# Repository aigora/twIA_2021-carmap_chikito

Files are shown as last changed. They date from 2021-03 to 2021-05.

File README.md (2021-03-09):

# CarMap - Chikito

Robot inalámbrico por Bluetooth que se conecta al ordenador. Con un teclado de macros o el mismo del ordenador se puede manejar. Además, el ordenador tiene en cuenta la trayectoria del robot para poder automatizar su vuelta. Dicha trayectoria se muestra en la pantalla, bien sea en forma del vector posición y rotación o mediante una curva.

## Integrantes del equipo

- Echedey Luis Álvarez. @echedey-luis-alvarez
- Fernando Moreno Santa Cruz. @Fer014
- Amélie Nader Prieto. @amelie-nader-prieto
- Luis Fernando Rubio Regojo. @luisrubio27
- Lucas Sánchez Solera. @luc-39
- Celia Torrecillas Barba. @Celia-t22

## Objetivos del trabajo

### Objetivos principales y mínimos:
- [] Crear un teclado de macros que simule un teclado usual.
- [] Hacer un pequeño robot inalámbrico por Bluetooth.
	- [] Capaz de moverse hacia delante y hacia atrás, y rotar sobre sí mismo. Se usarán drivers con motores DC.
- [] Hacer un programa en un ordenador que sea el intermediario entre cualquier método de entrada, como el teclado de macros, y el robot.
	- [] Estimar la posición del robot en cada momento según los comandos que envíe el programa.
	- [] Mostrar en alguna forma de interfaz la ubicación y rotación del robot.

### Objetivos secundarios, mejoras:
- [] Control de rotación de cada rueda mediante optoacopladores o pares LED IR - Sensor IR.
- [] Algoritmo para que el robot pueda volver sobre sí mismo
- [] Sistema para guardar posición, rotación, velocidad, (template de un robot) en un fichero.

## TODO:
- [] Wiki
- [] Crear logo
- [] Crear diagramas de flujo

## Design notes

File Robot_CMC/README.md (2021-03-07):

# Programa del robot inalámbrico
Programa de Chikito.
Un programa que permita recibir ordenes por bluetooth para que Chikito se mueva en todas direcciones.
Estará compuesto de un motor DC y este a su vez moverá unas ruedas.
Chikito podrá avanzar, retroceder y girar sobre sí mismo. 
En cada momento enviará al ordenador su posición para que se pueda crear su gráfica de posición.

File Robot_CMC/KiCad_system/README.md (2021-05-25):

# Sistema electrónico del Robot
En esta carpeta se encuentra el proyecto en KiCad del Robot _Chikito_. Se utilizan librerías personalizadas que se pueden encontrar en [este enlace](https://github.com/echedey-luis-alvarez/My_KiCad_Libraries).

Solo se emplea para exportar el esquema electrónico a imagen y realizar las explicaciones pertinentes.

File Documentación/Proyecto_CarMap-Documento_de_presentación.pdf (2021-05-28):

twIA_2021-CarMap_Chikito
Presentación del proyecto

# CarMap - Documentación

Repositorio: https://github.com/aigora/twIA_2021-carmap_chikito

## Miembros del grupo

Tag de GitHub en paréntesis
- Echedey Luis Álvarez (@echedey-luis-alvarez)
- Fernando Moreno Santa Cruz (@Fer014)
- Amelie Nader Prieto (@amelie-nader-prieto)
- Luis Fernando Rubio Regojo (@luisrubio27)
- Celia Torrecillas Barba (@Celia-t22)
- Lucas Sánchez Solera (@luc-39)
Todos (somos) estudiantes de primer año de Electrónica (grupo A109)

## Índice

- El proyecto
- Descripción del sistema
- Algoritmos
- Funciones y librerías
- Modificaciones del documento
- Enlaces de interés

# El proyecto CarMap

## Propósito del proyecto

Aunque a priori parece un proyecto cutre de estudiantes de primero de carrera (lo es) pretendíamos crear una aproximación bastante aproximada de lo que podría ser un robot que pueda ayudar en eventos catastróficos, en lugares que suponen un riesgo alto para los humanos. Sobra decir que el proyecto se queda lejos de la realidad, porque ni el Arduino UNO, ni nuestro tiempo ni nuestro nivel dan para tanto (por ahora).
Esencialmente no tiene mucha más utilidad que la de moverlo por un sitio e ir registrando su camino. Con este algoritmo, se podría estimar su posición, o moverse por sí mismo siguiendo una línea, tal vez llegar a volver por sí solo.

## Problema a resolver

Concretamos al principio del proyecto que este se trataría de un robot similar a un coche tele-dirigido y cuyo algoritmo le permite que su trayectoria se guarde en un mapa (fichero) y que el robot pueda “recordar” su trayectoria para poder regresar por el mismo camino que hizo. Además, queremos que sea fácil de manejar, para lo que intentaremos hacer algo similar a un mando radio-control.
Posteriormente consideramos que debido a la limitación del hardware y los requerimientos de la tarea, principalmente porque hay que manejar ficheros, lo que mejor se adapta es gestionar comandos y todo lo relativo a propiedades del robot en el PC, enviarlos y que el robot los ejecute.

# Descripción del sistema

Nuestro programa cuenta con tres subsistemas: por un lado haremos un teclado de macros (o HID, Human Interface Device) que permita manejar el robot. Por otra parte, un programa en el ordenador que tendrá el algoritmo más profundo en cuanto a manejar datos: entrada por teclado de los movimientos que hacer, exponer en la pantalla un mapa con los movimientos que va realizando el robot y algún otro dato, enviar datos al robot por Bluetooth y gestionar un fichero con la trayectoria. Finalmente, el robot, que deberá moverse en función de los comandos recibidos por Bluetooth.
En nuestro repositorio de GitHub se pueden ver varias carpetas. Estas son las que contienen a los códigos de los distintos subsistemas que hemos definido:
- Para el teclado de macros (HID): Teclado_Macros/
- Para el programa del PC: Mapeador/
- Para el robot: Robot_CMC/

Tanto el teclado de macros como el robot funcionan con Arduino. Asimismo, se programará el Mapeador en C con Visual Studio, aunque también tiene código en C++ para usar clases; en el mismo ejemplo de conexión por Bluetooth se utiliza la clase String, y en el Mapeador porque en las biblioteca SerialClass.h; también para la propia conexión se utiliza una clase.
Planteamos los problemas a resolver por distintas partes del proyecto antes mencionadas: el teclado de macros o HID, el programa en el PC (Mapeador), y el robot, que hemos querido bautizar como Chikito por cuestiones de marketing.

## Descripción detallada e identificación de sensores y actuadores

Este apartado fue escrito inicialmente en la Wiki del proyecto en GitHub después de discutir el tema entre todos en varias reuniones.

### Robot

- El Arduino se conecta al ordenador por Bluetooth
- Lucas Sánchez (@luc-39) se encarga del código en el Arduino.
■ Para poder conectar el software de Arduino con la placa que se encontrará en el robot es necesario usar un módulo bluetooth HC-05 que se encontrará en la protoboard. Además será necesario hacer uso de SoftwareSerial.h.
■ @Celia-t22 se encarga del movimiento de los motores mediante funciones.
- Se pueden incluir sensores como opto acopladores para monitorizar el giro de las ruedas. Al final esta parte no procede.

Para completar la información relacionada con el robot se utilizará el pdf

[3] de moodle
sobre la comunicación con Arduino y PC mediante bluetooth y la página
[4] sobre cómo usar
Arduino y C++.

### Mapeador

Tras una profunda lluvia de ideas se asignaron las siguientes tareas:
- Añadir función que calcule ángulo entre 2 vectores en vector.h para @Fer014.
- Maquetar una librería con propiedades del robot, de forma genérica, para alterarlas de forma más cómoda. Para @Fer014.
- Empezar con la entrada de comandos desde el teclado, que realizará @luisrubio27 con ayuda de la librería time.h.
- Se crearán vectores que se añaden a un array.
- Estos vectores dependen de la tecla; la dimensión del array, del tiempo presionado.
■ Sólo las teclas asociadas al movimiento (posición) del robot responden continuamente al mantenerse presionadas; en este proceso entran los vectores de posición y el tiempo total en el que la tecla se mantiene pulsada. Por tanto, los sensores serán el teclado del PC y el teclado de macros. No habrán actuadores per se, pero sí operaciones con los vectores y salida por la consola.

### Teclado de macros

Esta parte tiene que ser sencilla, implementando solo entradas digitales (pulsadores) y cuya actuación simula la pulsación de botones del teclado (conceptualmente, la actuación es una función programada, la cual puede ser pulsar una tecla o varias o hacer cualquier cosa más compleja). Desarrollándose por Amélie (@amelie-nader-prieto).
En resumen los sensores son los pulsadores del teclado y el actuador es la comunicación con el ordenador.

## Diseño del sistema por subsistemas

El contenido de este apartado fue también escrito inicialmente en GitHub tras una reunión del grupo, pero se ha actualizado ligeramente al ponerlo aquí.
Trabajamos en este paso a partir de las especificaciones hechas en la tarea anterior, de nuevo teniendo en cuenta los requisitos funcionales y no funcionales de hardware y código de las distintas partes del proyecto. Previamente a esta tarea definimos los datos que se manejan en distintas funciones del programa y se profundizó más en asuntos del hardware; en esta tarea nos interesa más trabajar en el software de nuestro proyecto; tanto en la estructura del programa principal ejecutado en el ordenador como en las aplicaciones de las plataformas auxiliares (robot y teclado).
En esta segunda reunión del equipo de desarrollo nos interesamos en aclarar, organizar y establecer los límites en el proceso de desarrollo que llevaremos individualmente sin perder de vista el trabajo en equipo. Necesitamos mantener cohesionado el proyecto y asegurar que las conexiones entre cada parte sean sólidas. A continuación exponemos en qué parte de la línea de la información se centra cada miembro, en función de cada apartado del proyecto:

### HID / Teclado de Macros

En la aplicación de PC para el teclado de macros se realizan las tareas de monitorización de las señales mediante funciones de SerialClass.h.
- Especificaciones y desarrollo por Amélie (@amelie-nader-prieto). Esta parte es la más simple en el código, pero se comunica directamente con el programa principal, y finalmente sirve como un dispositivo para controlar manualmente el robot.
- Las funciones (macros) aparecen programadas en el código de Arduino, y en la primera versión del proyecto se limitan a pulsar teclas.
- Para este propósito se puede considerar prescindible un teclado de macros, pero siempre se puede mejorar el código para que se puedan hacer funciones más complicadas del programa.
- Se utiliza la librería de Arduino Keyboard.h para utilizar el teclado, mediante funciones en las que no se pasan valores.

[9]

### Mapeador

En esta parte del proyecto establecemos aquellas funciones principales que queremos que se gestionen en el PC. Las partes más importantes son la entrada de datos mediante el teclado de macros, los cálculos relacionados con el Robot (el algoritmo), la escritura de ficheros, y la comunicación (envío de datos) por el puerto serie Bluetooth con el Robot.
- Especificaciones y desarrollo por @luisrubio27
- i. Diseñar el mapeador a través de la función gotoxy para imprimir un mapa que de a entender el recorrido del robot. Que se sitúe centralizado en la pantalla.
- ii. Diseñar el sistema brújula para que introduciendo las letras n, o, s, e se mueve en esa dirección tanto el mapa como el robot.
- iii. Introducir los datos de entrada para conectar el mapa con el algoritmo. Para posterior desarrollo de @Fer014.
- Especificaciones y desarrollo por @Fer014
i. Calcular el movimiento de las ruedas del robot, su avance y rotación, a partir de los datos recibidos y de la biblioteca "robot.h".
ii. Calcular las coordenadas de la posición del robot, para su posterior uso por @echedey-luis-alvarez.
- Especificaciones y desarrollo por @echedey-luis-alvarez
i. Escritura en fichero de los puntos por los que pasa el robot. Los puntos se toman del código a cargo de @Fer014 .
ii. Envío de datos por Bluetooth. Se acuerda entre todo el equipo que al robot se le pasará la cantidad de tiempo y el sentido en que debe girar cada rueda. Más concretamente, el formato de la cadena con el que se envía la información se aclarará con @luc-39 .

### Robot

- Especificaciones y desarrollo por @luc-39
i. Recibir los datos por Bluetooth desde el ordenador con ayuda de la librería SoftwareSerial.h. Para poder conectar el programa del ordenador con el del Arduino se verá con @echedey-luis-alvarez.
ii. Enviar la información recibida a @Celia-t22 y que así pueda operarse la última parte del código.
- Especificaciones y desarrollo por @Celia-t22
i. Recibo la información que manda @luc-39.
ii. Con esta información, los motores se moverán de forma que permita que Chikito se mueva en la dirección y el tiempo deseado.
iii. A continuación un esquema del movimiento de los motores:

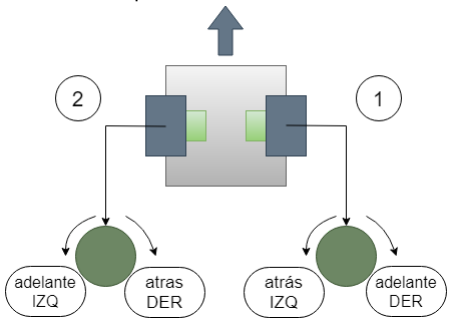
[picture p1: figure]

Este esquema representa los nombre que se le ha dado a cada movimiento en el código. Primero se ha puesto un nombre para cada distinguir cada motor, es decir “1” al motor que va a la derecha de chikito y “2” al que va la izquierda. Después, para representar si deseamos que la rueda gire hacia delante o hacia atrás, se ha representado como “IZQ” o como “DER”; estos nombre se han puesto así porque representan el lado que girará la rueda si se mira de frente.

## Entrada y salida de datos

Las entradas y salidas de datos se describen como una sucesión lineal entre las distintas partes del proyecto.

### Teclado de Macros

- Entrada: En el programa se realiza la lectura sucesiva de los pins digitales del controlador (los cuales son INPUT), y se guarda el valor (HIGH o LOW, donde LOW ocurre cuando el botón es pulsado) de todos ellos en un vector.

- Salida: El programa de Arduino no tiene datos de salida pues sus funciones no devuelven ningún valor, sino que pulsan las teclas N,S,E,O, que son las “flechas direccionales” con las que se dirigirá el robot en su movimiento. La salida no es un dato realmente, sino una acción que se realiza según los datos de entrada.
Dentro del mapeador están preparadas las bibliotecas y funciones más complejas que se ocupan de relacionar las señales recibidas del teclado con los comandos del robot (biblioteca de operaciones con vectores, biblioteca de propiedades del robot).

### Mapeador

- El programa recibe los datos digitales del teclado y realiza con ellos las funciones correspondientes.
- Se realizará un bucle switch/case con los comandos correspondientes a las teclas que realizan las funciones más básicas del robot (la tecla de encendido y de cambio de perfiles)
- A partir de las coordenadas se genera un array de los vectores de posición del robot.

### Robot

- Las variables y/o constantes necesarias serán manejadas en la biblioteca de propiedades del robot localizada en el mapeador.
- En los inicios del proyecto se planteó crear una estructura asociada al robot (template del robot) con únicamente tres variables distintas, pero decidimos posponer la definición de una estructura para otro momento.
- La conexión entre el robot y el ordenador será inalámbrica (Bluetooth).
- El robot funciona con una Arduino UNO Rev3 y la conexión Bluetooth con el módulo Bluetooth HC-05;
Coincidimos en que las especificaciones en el modo en que los valores obtenidos son almacenados y transmitidos entre las partes del proyecto, empleando ficheros y definiendo arrays numéricos (matrices) y vectores de estructuras se deja para fases más avanzadas; sin embargo tenemos una idea de los datos que es crucial manejar en el programa para que este pueda realizar su objetivo.
- Posición en el espacio expresada en coordenadas cartesianas
- Posición
- Rotación: ángulo en radianes o vector dirección
- Velocidad de movimiento
- Falta concretar las componentes y si habrá aceleración
Ahora bien, la salida se hace por un par de motores. Estos se controlan mediante dos circuitos integrados LB1641

[5]
, unos drivers bidireccionales que se controlan mediante dos pines digitales cada uno.

## Esquema electrónico del robot

A continuación se explica el funcionamiento del sistema electrónico que le da vida al robot. Los recursos diseñados en KiCad se pueden consultar en el repositorio.

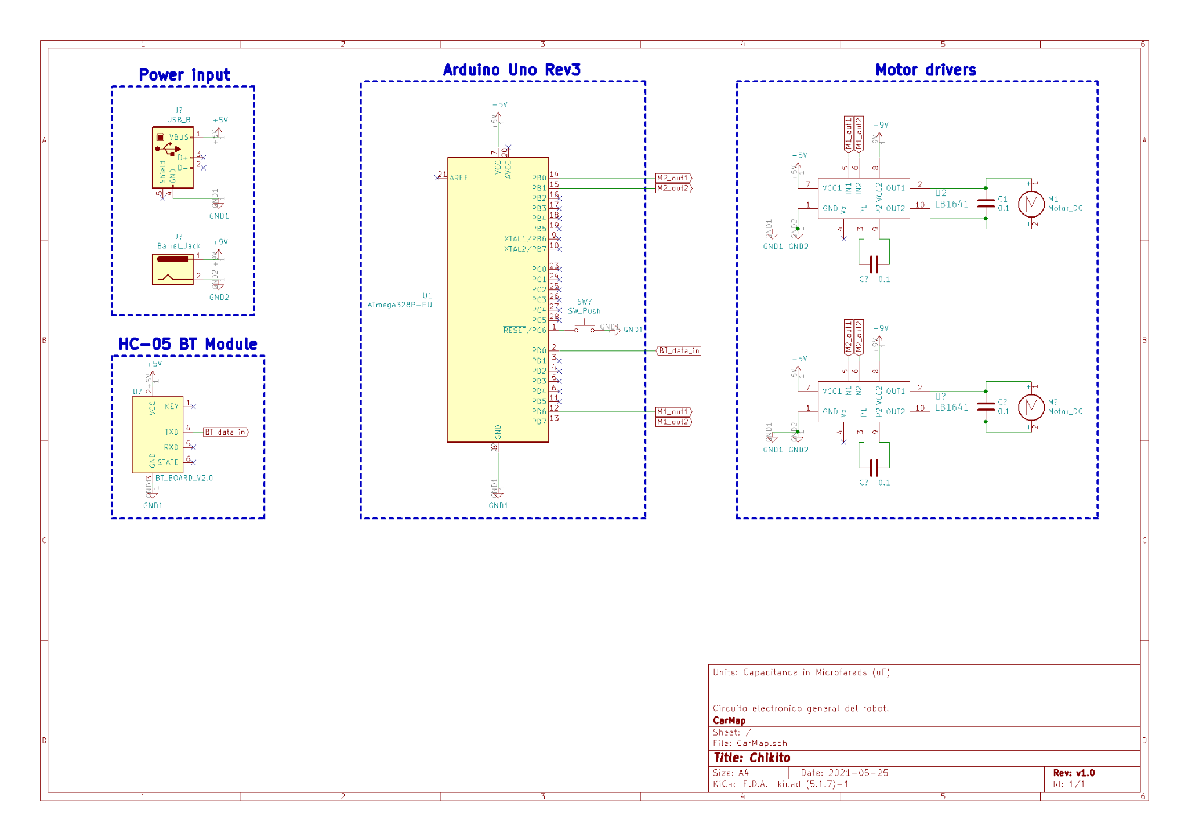
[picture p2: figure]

Lo que aquí se expone simplemente demuestra el funcionamiento del código, tal y como queda dicho en el vídeo, ya que no se ha probado con baterías y no se ha montado en una estructura, tan solo probado la parte electrónica.
Para comprobar la funcionalidad del sistema se han empleado:
1. Jumper wires para protoboard
2. Un par de protoboards
3. Un módulo Bluetooth de Keyestudio con el HC-05
4. Un Arduino UNO Rev3 con el chip ATmega328p
5. Un par de drivers LB1641 montados en una placa preperforada que contiene:
a. 2 drivers LB1641
b. 2 condensadores cerámicos de 0.01 uF
c. 2 condensadores cerámicos de 0.1 uF
d. Varios terminales para las conexiones oportunas
6. Un par de motores DC idénticos.

El circuito se monta tal y como viene en el previo diagrama electrónico.
1. En primer lugar, la potencia viene a 5V por un USB tipo B, que es el conectado al Arduino; y de algún otro voltaje (máximo 18V) para los motores
- se ha utilizado una fuente de red de 9V.

2. Los 5V alimentan la parte lógica: Arduino, módulo BT y el sistema lógico de los drivers.
3. La otra fuente alimenta la parte de potencia, es decir, los motores con los drivers de intermediarios.
4. Las señales lógicas que determinan en qué sentido se mueve cada motor son las que salen de los pines 6 a 9, dos por motor: como se puede consultar en el datasheet del LB1641

[5]
, cuando un pin está encendido y el otro apagado se mueve en un sentido. Si se intercambian estos pines, gira en el contrario. Si ambos están a nivel lógico HIGH o LOW no se mueven. Aunque no se especifica expresamente, se indica que en este último caso estarían en modo “Braking”, lo que implica que las salidas al motor estarían en corto y por autoinducción debería frenar antes.
5. Finalmente, el módulo Bluetooth se conecta desde su pin TXD (transmisión) al RX del Arduino (recepción), o sea, que el ATmega recibe la información enviada por el HC-05 que recibe desde el PC.

# Algoritmos y código como conjunto

A continuación se exponen cada una de las funciones que tienen lugar código. Para comentar cada librería que hemos creado o partes en específico que requieren más atención desde un punto de vista especialmente técnico vaya al apartado Funcionamiento de las distintas partes del código.

### Teclado de macros - HID

El HID funciona con un código escrito con el Arduino IDE y con un algoritmo no muy complejo.
1. El controlador se conecta con un cable al puerto COM3 del ordenador y es necesario conectarlo para que funcione el código.
2. En la función void loop() se realiza la lectura sucesiva de los pins digitales en los que están conectados los pulsadores, y guarda sus valores (HIGH o LOW) en un vector.
3. Si el programa detecta un LOW en la posición n del vector, llama a una función de parámetro n que se encarga de pulsar la tecla que corresponda mediante un switch. Esta función sirve para emular pulsaciones en el teclado del ordenador.
Y sobra ya decir que está incluida Keyboard.h.

Definiciones

#define N 6

#define S 7

#define E 8

#define O 9

Se definen los pins digitales que están conectados a cada pulsador, y que en la ejecución del programa son leídos sucesivamente al estar en un vector.
Además de estos, se podrían añadir otros botones asignados a cualquier otro pin del controlador (del 2 al 13), y programar funciones para ellos.
const int arrowpad[]={N,S,E,O};
Aunque es técnicamente una variable global, en Arduino no suele ser tan problemático porque se suelen manejar funciones que no modifican o devuelven valores numéricos. Además en este caso, tener definidas las constantes facilita la adición de nuevas teclas y funciones ya que la dimensión del vector arrowpad[] está declarado como const int, por lo cual se podría cambiar el vector sin tener que actualizar otras funciones o bucles.

Funciones
Son muy simples. Intenté hacer este programa corto, especialmente hacer la función principal (void loop()) lo más corta posible.
En setup() se inicializa el Serial, los pines del vector, y el teclado.
En loop() se realiza esta lectura sucesiva del vector con los botones, leyendo uno por uno los índices del vector, y si uno de ellos está pulsado, lo vuelve a leer y llama a, digamos la función del teclado;

key(i+1); donde el parámetro es una variable utilizada en el bucle donde se hacían estas lecturas; for(i=0;i<dim;i++){...} por lo cual i es el índice del vector en cada momento.
Esta es la función:
void key(int i){
switch(i){
case 1:north();break;
case 2:south();break;
case 3:east();break;
case 4:west();break;
default:break;
}
}
Y esas funciones llamadas en cada case son los comandos de Keyboard.h que pulsan las teclas en el ordenador; Keyboard.press(tecla); Keyboard.release(tecla); Los nombres de las teclas son valores definidos en Keyboard.h.

### Mapeador

Este programa utiliza una gran cantidad de librerías, ya que implementa muchas funcionalidades distintas entre sí; estas son:
Bibliotecas genéricas
1. stdio.h
a. Entrada básica de datos por consola (printf y scanf)
2. stdlib.h
a. Asignar memoria de forma dinámica
3. string.h
a. Permite realizar algunas operaciones con cadenas, se usa para crear los comandos del Robot.
4. wchar.h
a. Para utilizar caracteres “amplios”, i.e., que ocupan más de un byte. Esto se usa porque la biblioteca SerialClass.* nos daba un problema en el tipo de puntero al puerto utilizado que se pasaba al SO.
5. iso646.h
a. Posiblemente la librería que más aporte al programa: resulta más legible and, or y not que “&&”, “||” y “!” respectivamente. Sobre todo si vienes de Python.
6. math.h
a. Introduce las funciones trigonométricas y de redondeo que se usan para el mapa y el cómputo de coordenadas.
7. stdbool.h
a. Define los tipos bool si estás en C. En C++ ya vienen definidos. Esto es un poco por tontuna; es para la parte de crear los comandos, que tenga un poco el sentido binario que tiene, ya que se desplaza o rota, hacia delante o hacia atrás, hacia la izquierda o hacia la derecha.

8. conio.h
a. Introduce la función _getch() que permite tomar un carácter del búfer de entrada nada más se pulsa (como getchar(), pero esta última daba problemas y no funcionaba ubicar el búfer al final con
fseek(stdin, 0, SEEK_END) ).
9. windows.h
a. Para ubicar la posición del cursor en la consola ( gotoxy() ). Bibliotecas locales:
10. vector.h
a. Define la estructura vector2D y múltiples operaciones. Al final no se usa ni la mitad, pero aporta flexibilidad por si se quiere añadir alguna funcionalidad o refactorizar la parte del mapeador.
11. SerialClass/SerialClass.h
a. Añade la clase Serial (un tipo de dato de C++) para conectar por Bluetooth más fácilmente. Recuperada de https://github.com/Gmatarrubia/LibreriasTutoriales, modificada localmente.
12. waypoints_filehandler.h
a. Funciones que permiten inicializar, escribir y leer vectores del archivo de la trayectoria con el formato explicado en el apartado 2.4.1. Gestión del fichero en memoria.
En primer lugar se inicializa una ristra de variables que se utilizan durante la ejecución.
En segundo lugar, se le pide al usuario que indique por qué puerto COM se debe conectar al Arduino. Se intenta conectar, y si falla imprime el mensaje de error y se detiene la ejecución. Si es un éxito, se crea el archivo que va a guardar los vectores en binario y se inicializa. Si ocurriese algún error en esta parte, se detendría.
Si todo ha funcionado correctamente, imprime el estado del programa y los controles, para que el usuario sepa cómo proceder. Tras una pulsación que se haga en el teclado, se limpia lo escrito por pantalla, se inicializa el mapa y la posición del robot.
Una vez en el bucle, se espera a una pulsación del usuario, y si está definida (n, s, e, o) se crea un comando que se envía por Bluetooth. En caso contrario no se hace nada. Si se envía el comando, se cambia la posición en el mapa del robot y se vuelven a mostrar la posición, la distancia recorrida y la distancia desde el origen.
Por último, cada vez que se envía un comando se añade el vector al fichero y se espera el tiempo necesario a que espere de

### Robot

El esquema de la protoboard con el módulo bluetooth HC-05 sería el siguiente:

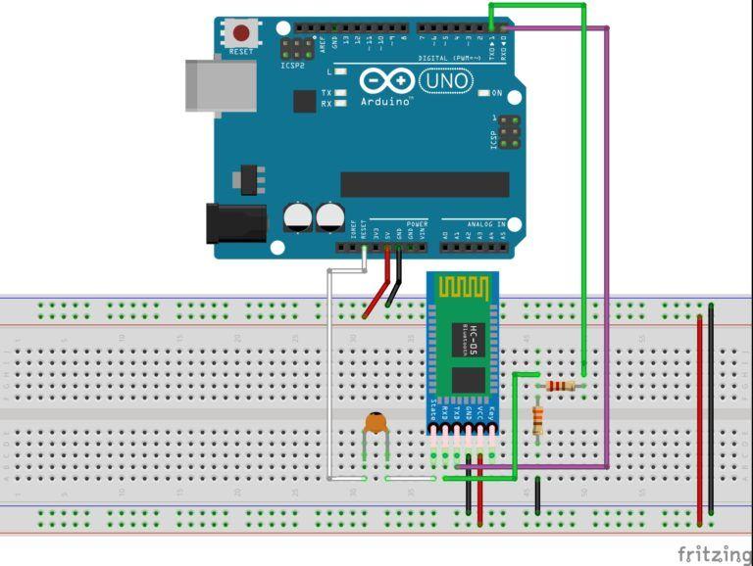
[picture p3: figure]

Anotación: Es necesario que la resistencia esté ya que del pin TX salen 5V y el módulo bluetooth HC-05 admite un voltaje más bajo, unos 3,3V.

Para poder configurar el módulo bluetooth se utilizan los comandos 'AT':

- 'AT+NAME'. Se define el nombre del dispositivo.
- 'AT+PSWD'. Se define la contraseña (PIN) del módulo bluetooth para cuando nos queramos conectar con el bluetooth.
- 'AT+UART'. Sirve para los parámetros de la comunicación, como la velocidad.
- 'AT+ROLE'. Se utiliza para indicar el rol del módulo: si es un 0 su rol es el de esclavo (recibe los datos del maestro) y si es un 1 su rol es el de maestro (envía los datos al esclavo).
- 'AT+ORGL'. Restaura los valores de fábrica.
- 'AT+RESET'. Vuelve al modo usuario. Sirve para salir del modo de configuración.

Estos comandos se pueden usar de dos formas:

- 'COMANDO?'. Lectura del valor, no lo modifica.
- 'COMANDO='. Asigna un valor al comando.

Para poder usar estos comandos es necesario primero que el módulo esté en modo configuración. Para ello hay que presionar durante los cinco primeros segundos de encendido el botón que tiene el módulo bluetooth hasta que los leds estén parpadeando de forma lenta, si parpadean rápido quiere decir que se encuentra en modo usuario.

Una vez subido el programa del bluetooth a la placa Arduino es necesario abrir el monitor serial y verificar la configuración de este: habilitar autoscroll, habilitar Ambos NL & CR en los ajustes de línea y ajustar la velocidad a 9600 baudios. Una vez hecho esto se puede empezar a configurar el módulo bluetooth con los comando 'AT' escribiéndolos en el monitor serial. Una vez finalizado el proceso de configuración se introduce el comando 'AT+RESET' para salir al modo usuario y poder emparejarlo mediante bluetooth.

Programa básico del módulo bluetooth:

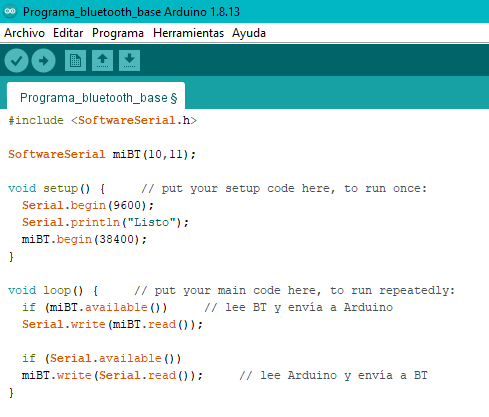
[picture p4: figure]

# Funcionamiento de las distintas partes del código

Mapeador: | procesamiento | pulsaciones, | cálculo | de

## coordenadas y mapa

### Objeto

En este apartado se detalla el funcionamiento del Mapeador. Este término engloba al conjunto de funciones encargadas de recibir las pulsaciones del teclado de macros, calcular las coordenadas del robot y el tiempo que se debe mover, y dibujar en la consola un mapa que muestre la trayectoria del robot.

### Definiciones

El programa utiliza una serie de constantes definidas por el usuario:

#define WHEEL_RADIUS: Radio de las ruedas del robot (m).

#define ROBOT_WIDTH: Distancia existente entre las dos ruedas del robot (m).

#define WHEEL_TURN: Número de giros que las ruedas del robot realizan hacia delante o hacia atrás, tras cada pulsación.

#define ROT_ANGLE: ángulo que el robot rota a derecha o izquierda (rad), tras cada pulsación.

#define ANGULAR_VELOCITY: Velocidad angular a la que rotan las ruedas del robot (rad/s).

### Funciones

1. int ProcessPulsation(pulsation* p_pulsation, int inputChar)
a. Recibe la información transmitida por el teclado de macros (HID), detecta el tipo de pulsación que se ha producido (n, s, e, o), y contabiliza el número total de pulsaciones de cada tipo.

Argumentos:

i. p_pulsation: puntero a estructura que almacena el tipo de pulsación y el número total de estas.
ii. | inputChar: recibe un carácter del teclado a través de la función
| _getch.

2. void | Calc_Coordinate_Time(pulsation* | p_pulsation, | coordinate*
p_coord, tiempos* p_time)
a. Calcula las coordenadas (en metros) a las que se desplaza el robot tras cada pulsación.
b. Calcula el ángulo de rotación (en radianes) del robot respecto de la posición inicial (mirando en la dirección positiva del eje OY) tras cada pulsación. El conocimiento de este ángulo es necesario para poder calcular las coordenadas de manera efectiva, puesto que el robot debe ser capaz de desplazarse en todas las direcciones. La rotación hacia la derecha se expresa con un ángulo positivo, mientras que la rotación hacia la izquierda se expresa con un ángulo negativo.
c. Calcula el tiempo (en segundos) que el robot debe realizar cada uno de sus movimientos básicos (avanzar, retroceder, rotar hacia la derecha y rotar hacia la izquierda) tras cada pulsación.
d. Calcula la distancia recorrida por el robot, la distancia del robot respecto al origen de coordenadas, e imprime en pantalla las coordenadas del robot y las dos distancias anteriores.

Argumentos:

i. p_pulsation: puntero a estructura que almacena el tipo de pulsación y el número total de estas.
ii. p_coord: puntero a estructura que almacena las coordenadas del robot, el ángulo de rotación del robot, y la distancia recorrida por este, tras cada pulsación.
iii. p_time: puntero a estructura que almacena el tiempo que el robot debe avanzar, retroceder, rotar hacia la derecha y rotar hacia la izquierda, tras cada pulsación.

El cálculo de los anteriores parámetros (coordenadas y tiempos) es posible gracias a la utilización de fórmulas matemáticas y físicas (movimiento circular uniforme). En concreto:

I) S = 2 · π · R | (Longitud de la circunferencia de la rueda). wℎeel
| · Wℎeel turn
II) S = R | (Para calcular el avance y retroceso del robot). wℎeel
| · ω · t

III) S = α · Robotwidtℎ

( / 2)

Sustituyendo I) en II) y despejando t tenemos:

IV) t = (2 · π · Wℎeel | (Para calcular el tiempo que el robot avanza y
| turn ) / (ω)
retrocede).

Igualando II) y III) y despejando t tenemos:

V) t | (Para calcular el tiempo que el
r = (α · Robotwidtℎ

) / (2 · ω · R
wℎeel

)
robot rota a derecha o izquierda, tras cada pulsación).

Donde:

- S: Distancia recorrida por el robot al avanzar o retroceder (m), tras cada pulsación.
- t: Tiempo que el robot avanza o retrocede (s), tras cada pulsación.
- t : Tiempo que el robot rota a derecha o izquierda (s), tras cada pulsación.
r
- ω: Velocidad angular a la que rotan las ruedas del robot (rad/s). Definida
anteriormente como #define ANGULAR_VELOCITY.
- α: Ángulo que el robot rota a derecha o izquierda (rad), tras cada pulsación. Definido anteriormente como #define ROT_ANGLE.
- R : Radio de las ruedas del robot (m). Definido anteriormente como
wℎeel
#define WHEEL_RADIUS.

- Wℎeel : Número de giros que las ruedas del robot realizan hacia delante o
turn
hacia atrás, tras cada pulsación. Definido anteriormente como #define
WHEEL_TURN
- Robot : Distancia existente entre las dos ruedas del robot (m). Definido
widtℎ
anteriormente como #define ROBOT_WIDTH.
3. void DrawMap(coordinate* p_coord)
a. Imprime en pantalla el carácter “#”, que representa la posición del robot, sobre unos ejes cartesianos dibujados previamente. Para mostrar la posición del robot en el mapa, sabiendo sus coordenadas, se hace uso de la función gotoxy. Los puntos del mapa por los que se ha desplazado el robot tras cada pulsación quedan reflejados y guardados en el mapa, lo cual nos permite conocer su trayectoria.
b. Imprime en pantalla el carácter “+”, siempre junto al carácter “#” del robot, y colocado respecto a este de manera que señale la dirección en la que está orientado el robot.

Argumentos:

i. p_coord: puntero a estructura que almacena las coordenadas del robot, el ángulo de rotación del robot, y la distancia recorrida por este, tras cada pulsación.

Para que el movimiento del robot en el mapa sea uniforme, y no dependa del radio de las ruedas ni de π, se aplica un factor de corrección en ambos ejes OX y OY.

4. void gotoxy(short x, short y)
a. Permite situar el cursor a un punto determinado de la pantalla de manera que cualquier función de impresión que se ejecute a continuación aparecerá a partir de ese punto. Es necesaria para imprimir en pantalla los ejes y la posición del robot.

Argumentos:

i. short x: Componente X del punto buscado. ii. short y: Componente Y del punto buscado.
5. void clearScreen(int spaces)
a. Limpia cantidad de caracteres en pantalla, sustituyéndolos por espacios en blanco.
b. Argumentos
i. spaces: Cantidad de caracteres que se desea limpiar

## 2.4.1. Gestión del fichero en memoria

### Objeto

En este apartado se detalla el funcionamiento del tratamiento del archivo que almacena la trayectoria en forma de puntos. Más concretamente, se tratará de explicar el funcionamiento del código declarado en waypoints_filehandler.h y definido en waypoints_filehandler.cpp. A pesar de estar en formato .cpp, el código está escrito en
C. Es para evitar un incómodo error que ocurre cuando se utilizan archivos .cpp y .c simultáneamente en VS: LNK2019.

### Dependencias

- Biblioteca locales:
- vector.h: los puntos se declaran como vectores bidimensionales, i.e. estructuras vector2D.
- Bibliotecas genéricas:
- stdio.h: manipulación básica de los ficheros.
- stdlib.h: asignación dinámica de memoria.
- time.h: creación de la estampa de tiempo para hacer los archivos únicos
- string.h: copia y obtención de largo de cadenas. Funciones strcpy_s() y strlen(), para crear el nombre de archivo.

- inttype.h: creación de variables de tipos de ancho fijo.

### Archivo

El archivo que se utilizará será en binario, es decir, los datos se guardan tal y como las variables están en la RAM (en nuestro caso dos tipos, un uint32_t y una estructura vector2D). Esto facilita la búsqueda de un dato en concreto, especialmente porque no me aclaro con los finales de línea y los scanf_s().
En primer lugar se guarda una variable con la cantidad de puntos que se han escrito en él. Esto permite facilitar la lectura (o, incluso, la asignación de memoria dinámica a un array de puntos). Esta es la variable uint32_t. Esta primera variable está definida en todo el programa como uint32_t (estándar C11), lo que implica que el tamaño que ocupa tanto en memoria como en el fichero es de 32 bits o 4 bytes independientemente de la arquitectura del sistema / OS que se utilice. Aplicando el mismo razonamiento para el tamaño de las estructuras vector, 2 tipos double deberían ocupar 128 bits (16 bytes): según la IEEE 754 ocupan 64 bits u 8 bytes cada uno. Esto puede cambiar entre sistemas en casos muy reducidos

[7]
, fuera del estándar.
El resto de información en el fichero son chunks de estructuras que representan cada punto, tantos como se especifica en la primera variable. La dimensión de cada chunk de estos debería ser consistente entre distintos PCs, ya que los tipo double siempre deben de medir lo mismo (8 bytes, por lo que la estructura vector2D mide 16 bytes).

### Ejecución

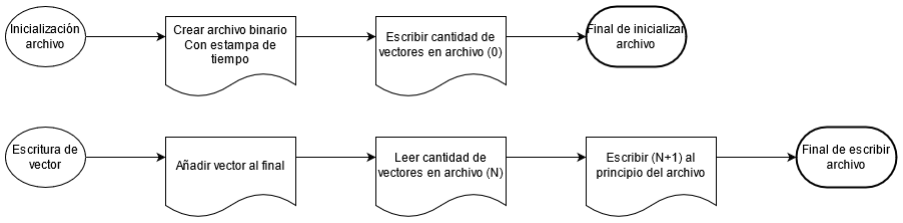
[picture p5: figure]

Diagrama de ejecución de las funciones que inicializa el archivo y escribe un vector en él

Lo primero es inicializar el archivo con waypts_bcreate_file(). Este lo crea en binario con el nombre especificado o uno generado en función de la fecha y hora, minuto y segundo. Posteriormente añade la primera variable, el número de vectores que contiene en ese momento (0). Se genera automáticamente cuando la cadena está vacía o se usa la macro MODE_TIMESTAMP (equivalente a "\0") en el argumento del nombre. Además, el modo es de lectura y escritura (que si no existe se crea) en binario. Esto último es importante para que la función de añadir puntos luego funcione correctamente.
Cada vez que se quiere añadir un punto de la trayectoria, se hace una llamada a la función waypts_bappend_vect(). Esta coge el vector que se le ha pasado y lo concatena al final del archivo. Si pudo, ahora va al principio a leer la cantidad de vectores que el archivo dice haber, lo incrementa en 1, vuelve al principio y lo escribe de nuevo. Así queda actualizado el archivo finalmente. Si en algún momento no puede realizar alguna operación se devuelve un error. El archivo, si se hubo modificado, modificado quedó.
Por último, para hacer la lectura de un vector, se usa waypts_bread_vect(); los argumentos que necesita son el archivo de puntos, el array o puntero a vector al que se va a escribir los datos leídos, el tamaño de este búfer, desde qué posición se desea leer, y qué cantidad de puntos se desea obtener. Lo primero que hace es colocar la posición del búfer en un offset equivalente al tamaño de la primera variable más la posición del vector a leer por el tamaño de cada vector2D.

### Macros

Macro | Valor
MODE_TIMESTAMP | "\0"

### Funciones

1. int waypts_bcreate_file(FILE** fp, const size_t sz, const char filename[], char* assigned)
a. Crea e inicializa el archivo de puntos por los que pasa el robot. Devuelve cero si consigue hacer el archivo [devuelve lo mismo que fopen_s() o fwrite() al inicializarlo]. Argumentos:
i. fp: puntero a puntero de archivo (FILE*) (se modifica),
ii. sz: tamaño máximo del nombre archivo
iii. filename: nombre archivo o protocolo a utilizar (MODE_TIMESTAMP ó "\0" para usar la estampa de tiempo)
iv. assigned: puntero a nombre asignado al archivo finalmente, tamaño mayor o igual al especificado en sz
b. Devuelve los errores (0 indica éxito):
i. 100: no puede asignarse memoria dinámica
ii. 150: el nombre especificado no es adecuado (salida por pantalla del error)
iii. Ó el retornado por fopen_s o feof. Puede coincidir con alguno de los anteriores
2. int waypts_bget_nvects(FILE* fp, uint32_t* dest)
a. Toma la cantidad de puntos en un archivo con el formato aquí descrito y lo escribe en dest. Argumentos:
i. fp: puntero al archivo
ii. dest: puntero a variable a la que se asigna la cantidad de puntos
b. Devuelve 0 si funciona correctamente.
3. int waypts_bappend_vect(FILE* fp, vector2D* src)
a. Añade 1 vector de dos componentes (src´) al archivo apuntado por fp`, en binario Argumentos:
i. fp: puntero a archivo que se modifica ii. src: vector que se concatena al archivo
b. Devuelve 0 si funciona correctamente.
4. int waypts_bread_vect(FILE* fp, vector2D* dest, size_t bufferSize, uint32_t start, uint32_t N)
a. Lee N-vectores desde el punto en la posición start
ii. | fp: puntero a archivo desde el que se lee
iii. | dest: puntero a array de vectores en el que se guardan los valores
iv. | bufferSize: tamaño del array (puede ser sizeof(vector2D))
v. start: elemento desde el que se empieza a leer (el primer elemento
| tiene la posición 0)
vi. | N: cantidad de vectores a leer
b. Devuelve 0 si funciona correctamente. En caso de error sale con un código mayor de 210.

# Versiones del documento: Fecha e historial de

modificaciones en el documento.

El documento fue creado el 7 de Mayo de 2021 para coincidir con la primera entrega del proyecto, aunque gran parte de la información detallada aquí proviene de documentos que ya existían en la Wiki del proyecto, creados durante el último mes mayoritariamente.
A lo largo de las tres semanas siguientes al 7 de mayo fuimos editando el documento para entregarlo a tiempo el día 28 junto con el proyecto terminado y un vídeo explicando todo.
Queremos poner toda la información acerca del funcionamiento del proyecto a nivel de código y sistemas, y dejar la wiki y el readme para las especificaciones más prácticas y de uso una vez esté enteramente funcional.

Historial de las modificaciones:
- 7 de mayo: Creación del documento
- 15 de mayo: Actualización del primer apartado (problemas a resolver)
- 16 de mayo: Reunión de grupo y actualización entre todos
- 20 de mayo: Nueva actualización (teniendo en cuenta sugerencias y comentarios anteriores)
- 23 de mayo: Nueva actualización, reubicando párrafos y cambiando títulos
- 25 de mayo: Nueva actualización; añadir Esquema electrónico del robot y actualizado Algoritmos y código como conjunto
- 27 de mayo: Añadir partes faltantes y último repaso.

# Enlaces

### 1. Wiki; Descripción detallada de sensores y actuadores

https://github.com/aigora/twIA_2021-carmap_chikito/wiki/1.-Descripci%C3%B3n-deta llada-e-identificaci%C3%B3n-de-sensores-y-actuadores
2. Wiki: Diseño del sistema https://github.com/aigora/twIA_2021-carmap_chikito/wiki/2.-Dise%C3%B1o-del-Siste ma
3. PDF en moodle
https://moodle.upm.es/titulaciones/oficiales/pluginfile.php/9266173/mod_resource/content/1/Comunicaci%C3%B3n_Bluetooth_Arduino_PC.pdf (https://moodle.upm.es/titulaciones/oficiales/pluginfile.php/9266173/mod_resource/content/1/Comunicaci%C3%B3n_Bluetooth_Arduino_PC.pdf)
4. Página consultada sobre Arduino y C++ https://geekytheory.com/como-usar-arduino-y-cplusplus
5. LB1641 Datasheet
https://www.alldatasheet.com/datasheet-pdf/pdf/439406/SANYO/LB1641.html

6. Github - Gmatarrubia/LibreriasTutoriales https://github.com/Gmatarrubia/LibreriasTutoriales
7. Precisión doble (Wikipedia) https://en.wikipedia.org/wiki/Double-precision_floating-point_format
8. KiCad_system en Robot_CMC https://github.com/aigora/twIA_2021-carmap_chikito/tree/master/Robot_CMC/KiCad_system (https://github.com/aigora/twIA_2021-carmap_chikito/tree/master/Robot_CMC/KiCad_system)
9. Arduino: Keyboard.h reference https://www.arduino.cc/reference/en/language/functions/usb/keyboard/

## Otros sitios consultados durante el desarrollo

- Repositorio de un exalumno que dio una charla en el CREA sobre un teclado de macros: https://bitbucket.org/AlexAlc/macro_keyboard/src/master/
- Más teclados de macros:
- https://youtu.be/adVdUyBJf6E
- https://youtu.be/72a85tWOJVY
- Quitar el debouncing en pulsadores:
- https://www.eejournal.com/article/ultimate-guide-to-switch-debounce-part-4/
- Pinout del Arduino UNO, para realizar el modelo en KiCad.
- https://www.circuito.io/blog/arduino-uno-pinout/
- Recursos publicados en Moodle:
- Paradigma modular
- Diseño del sistema
- Comunicación Bluetooth Classic: Arduino - Visual C++ 2019
- Gotoxy en Dev-C++

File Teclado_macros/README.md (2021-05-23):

## Programa del teclado Arduino
El objetivo de esta parte del proyecto era crear una interfaz que pueda controlar los movimientos del robot; más específicamente, programar los botones para que, al pulsarlos, ejecuten cada uno una función dentro del programa (un teclado de macros, pero diseñado para CarMap)

En la primera versión, el teclado únicamente es capaz de _escribir_ las letras 'n','s','e' y 'o' (los motores del robot están programados para reaccionar a ellas). El verdadero potencial reside en que, si en algún momento en el futuro se añaden nuevas funciones al programa principal, se puedan añadir más teclas o _perfiles_ del teclado que permitan realizar dichas funciones rápidamente.

Para usar: Se tiene que conectar el controlador (el cual tiene dentro el código) al ordenador, y ejecutar el programa Mapeador y el Robot, que se mueve pulsando las teclas:
 - N: mover hacia adelante
 - S: retroceder
 - E: girar a la derecha
 - O: girar a la izquierda

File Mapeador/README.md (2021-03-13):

# Programa principal
Programa que va en el ordenador para manejar el mapa.
Guarda la posición en el espacio de CarMap y muestra su trayectoria.

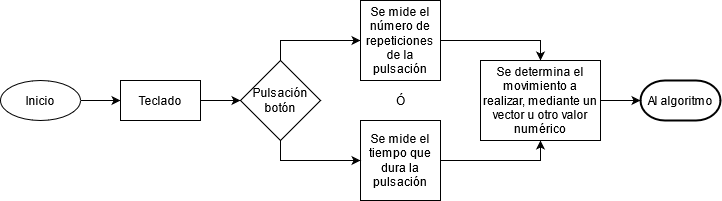
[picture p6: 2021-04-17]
Images/02-EntradaTeclado.png

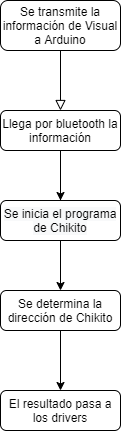
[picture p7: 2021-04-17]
Images/Diagrama parte Lucas.png

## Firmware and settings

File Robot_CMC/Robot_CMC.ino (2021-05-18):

/*  Project: CarMap - Chikito
 *  This file is the main program for the robot Chikito.
 */
// Referencas a Bibliotecas

// Enumeraciones que facilitan la lectura del código

// Variables globales

//Motor 1 es el motor de la derecha
#define motor1_IZQ 6
#define motor1_DER 7

//Motor 2 es el motor de la izquierda
#define motor2_IZQ 8
#define motor2_DER 9

void setup()
{
  // put your setup code here, to run once:
  // Tareas de configuración 
  Serial.begin(9600);

  pinMode(motor1_IZQ,OUTPUT);
  pinMode(motor1_DER,OUTPUT);
  
  pinMode(motor2_IZQ,OUTPUT);
  pinMode(motor2_DER,OUTPUT);
}

//Prototipos de función de movimiento
void parar();
void delante();
void atras();
void derecha();
void izquierda();

//Prototipos de función de motores
void motor1DER();
void motor1IZQ();

void motor2DER();
void motor2IZQ();

void motor1PARA();
void motor2PARA();

void loop()
{
  // put your main code here, to run repeatedly:
  if (Serial.available() > 0)  // Si hay mensajes procedentes del PC  
    procesar_accion();
    
  delay(50);
} 

// Resto de acciones 

int procesar_accion(void)
{
  unsigned int tiempoMilis=0;
  char movimiento[4],sentido[4],tiempo[6];
  String cadena = Serial.readStringUntil('\n'); // Lee mensaje
  if(cadena[0]=='t' && cadena[1]==':') 
  {
    for(int i=0;i<3;i++)
    {
      movimiento[i]=cadena[i+2];
    }
    movimiento[3]=0;
    for(int j=0;j<3;j++)
    {
      sentido[j]=cadena[j+6];
    }
    sentido[3]=0;
    for(int k=0;k<5;k++)
    {
      tiempo[k]=cadena[k+11];
    }
    tiempo[5]=0;
    tiempoMilis= atoi(tiempo);
    if(strcmp(movimiento,"lin")==0)
    {
      if(strcmp(sentido,"del")==0){
        delante(); //Movimiento lineal hacia delante
      }
      else if(strcmp(sentido,"atr")==0){
        atras(); //Movimiento lineal hacia atrás
        
      }
      else{
      //Error
      return 20;  
      }
    }
    else if(strcmp(movimiento,"rot")==0){
      if(strcmp(sentido,"der")==0){
        derecha(); //Movimiento rotacional hacia la derecha
      }
      else if(strcmp(sentido,"izq")==0){
        izquierda(); //Movimiento rotacional hacia la izquierda
      }
      else{
        //Error
        return 15;
      }
    }
    else{
      //Error
      return 10;
    }
  }
  else{
    //Error
    return 1;
  }
  delay(tiempoMilis);
  parar(); //Parar
  return 0;
}

//Cuerpos de funciones de movimiento
void parar()
{
  motor1PARA();  
  motor2PARA();
}

void delante()
{
  motor1DER();
  motor2IZQ();
}

void atras()
{
  motor1IZQ();
  motor2DER();
}

void derecha()
{
  motor1DER();  
  motor2DER();
}

void izquierda()
{
  motor1IZQ();
  motor2IZQ();
}

//Cuerpos de funciones de motores
void motor1DER()
{
  digitalWrite(motor1_IZQ,LOW);
  digitalWrite(motor1_DER,HIGH);
}

void motor1IZQ()
{
  digitalWrite(motor1_IZQ,HIGH);
  digitalWrite(motor1_DER,LOW);
}

void motor2DER()
{
  digitalWrite(motor2_IZQ,LOW);
  digitalWrite(motor2_DER,HIGH);
}

void motor2IZQ()
{
  digitalWrite(motor2_IZQ,HIGH);
  digitalWrite(motor2_DER,LOW);
 
}

void motor1PARA()
{
  digitalWrite(motor1_IZQ,LOW);
  digitalWrite(motor1_DER,LOW);
}

void motor2PARA()
{
  digitalWrite(motor2_IZQ,LOW);
  digitalWrite(motor2_DER,LOW); 
}

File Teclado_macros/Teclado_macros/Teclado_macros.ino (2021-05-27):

/*  Project: CarMap - Chikito
 *  This file is the main program for the macro keyboard.
 */
#include <Keyboard.h>

/*"north/south/east/west" buttons are connected to pins 6,7,8,9*/
#define N 6
#define S 7
#define E 8
#define O 9
//
/*array of the button pins and size of arrays are used by all functions but now modified
usage of global variables is acceptable in this context*/
const int arrowpad[]={N,S,E,O};
const int dim=sizeof(arrowpad)/sizeof(int);

/*initializes Serial and sets button pins as input*/
void setup() {
  Serial.begin(9600); while(!Serial){;}
  int i;
  for(i=0;i<dim;i++){ pinMode(arrowpad[i],INPUT_PULLUP); }
  Keyboard.begin();
  }

/*push buttons trigger the corresponding Macros when pressed*/
void loop(){
  int button_now=HIGH,buttons_prev[]={HIGH,HIGH,HIGH,HIGH},i;
  for(i=0;i<dim;i++){
    button_now=digitalRead(arrowpad[i]);
    Serial.println(button_now);
    if(button_now==LOW&&buttons_prev[i]==HIGH){
      delay(100); button_now=digitalRead(arrowpad[i]);
      if(button_now==LOW){key(i+1);delay(100);}
      else{delay(200);}
      }
      delay(300);
    }
  }

/*this function receives the number of the pressed pin and calls another function*/
void key(int i){
  switch(i){
    case 1:north();break;
    case 2:south();break;
    case 3:east();break;
    case 4:west();break;
    default:break;
    }
  }
/*functions called in every case*/
void north(){
  Serial.println("pressing key: N");
  Keyboard.press('n');
  Keyboard.release('n');
  delay(100);
  }
void south(){
  Serial.println("pressing key: S");
  Keyboard.press('s');
  Keyboard.release('s');
  delay(100);
  }
void east(){
  Serial.println("pressing key: E");
  Keyboard.press('e');
  Keyboard.release('e');
  delay(100);
  }
void west(){
  Serial.println("pressing key: O");
  Keyboard.press('o');
  Keyboard.release('o');
  delay(100);
}

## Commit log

2021-03-06 Crear carpetas y readme's
    Primeras carpetas de trabajo y sus respectivos readme para cada parte del proyecto creados e inicializados.
2021-03-06 Actualizar README principal
    Faltan dos compañeros por añadir.
    Se detallan los requerimientos de nuestro proyecto.
2021-03-07 nada importante
    [boceto_macro.dwg]
2021-03-07 nevermind
    xd perdón
    [boceto_macro.dwg]
2021-03-07 Actualizar README Principal
    Añadidos el resto de enlaces y usuarios del equipo
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2021-04-02 Crear carpeta images
    He metido el logo en la carpeta images para no tener tantas cosas sueltas. La próxima vez que alguien quiera subir una foto desde el ordenador que la suba a esta carpeta primero para poder copiar el 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
2021-04-03 Reubicar logo.png
    El logo debe estar en el directorio principal.
    Véase https://github.com/aigora/punto_inicio/wiki/6.-C%C3%B3mo-presentar-el-trabajo , el sexto apartado
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2021-04-16 programa que detecta la pulsacion de un boton
    detecta la pulsacion rastreando la palabra 1 viendo el numero de veces que se repite
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2021-04-17 Diagrama
    No sé si el diagrama está bien. Si hace falta decídmelo pls.
2021-04-17 Diagramas
    No sé si el diagrama está bien. Si hace falta cambiar/quitar/añadir algo decídmelo pls.
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2021-04-17 Reordenar fuente diagramas
    @luc-39 , no vi el del directorio principal. Lo meto en Images/
2021-04-22 Major update: File handling (first approach), lots of comments
    Archivos: se genera un archivo en el directorio raíz exclusivamente cuando se puede conectar el Arduino. En este se grabarán los puntos que se van generando y generan la trayectoria del robot.
2021-04-23 Añadidos archivos de proyecto; .gitignore ahora los permite modificar
    Rectificados los pasos. Perdón por la confusión y las dificultades técnicas ocasionadas.
2021-04-24 Actualizado el código a C++ finalmente (compatibilidad con los ejemplos de Moodle y el resto de funciones)
    Bugfix: error al linkear LNK2019 funciones de librerias propias en .c
    Solucionado pasando formato a .cpp
    No se altera el código en C
2021-04-24 Reorganizar código gestión ficheros, añadidas funciones y reimplementada la creación de archivo
    @Fer014 aquí tienes el código que puedes usar para guardar vectores. La lectura la dejamos para otro momento, aunque ya implementé una pequeña función porque me veía con ganas. Y tal vez se venga una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
    Changelog:
    - Creadas librerías específicas para la gestión de archivos
    - Renombrar createWaypoints_file() por waypts_create_file()
    - Ahora todas las funcs que se relacionan con el archivo empiezan por waypts_*
    .- Cambio a modo binario y lectura y escritura simultánea (con el formato texto no me enteraba)
    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
2021-04-24 Añadidos ejemplos relativos a los últimos cambios
    @Fer014 te dejo un ejemplo de escritura y lectura de puntos. Ya tú sabe papi que solo tiene que escribir en el fichero.
    @luc-39 te añadí la función de lo que hablamos; es bastante poco, pero ahí está por si necesitas modificar algo del protocolo. Eso ya lo ves tú cuando te pongas.
    - Añadida función formato del protocolo de tiempo
    - Pequeño cambio de tipo de variable por consistencia
    - Añadidos los ejemplos
    - Eliminada createWaypoints_file() que ahora está en waypoint
    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
2021-04-25 Mapa y botones-temporizador
    Es mas o menos la idea base que tengo
    para solucionar las partes del proyecto que me tocan
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2021-04-26 Update test_coordinates.cpp
    He "discretizado" la función anterior para que pueda recibir el numero de pulsaciones de cada botón (o en su defecto el tiempo pulsado).
2021-04-26 Update mototres
    He corregido los errores del anterior programa, no esta acabado y queda por hacer.
    [Robot_CMC.ino]
2021-04-28 Sustituir tipo errno_t por int, para seguir las especificaciones de la C11
2021-04-28 Soporte para múltiples arquitecturas de la gestión del fichero
    Cambiar size_t por uint32_t la variable que se asigna en el primer elemento del archivo. De esta forma se pueden transferir archivos entre distintos PCs sin que el tamaño varíe
2021-04-28 Refactorizar, añadir waypts_bget_nvects y mejorar consistencia del programa
    @Fer014 aquí te dejo nuevos ejemplos
    @Fer014 y @luc-39 , para poder ver los ejemplos hay que hacer un bypass del if(Arduino->isConnected) poniendo un "or 1" dentro del if.
    - Nueva función waypts_bget_nvects() para obtener la cantidad de vectores en el archivo, sin validación de datos. Véase Wiki o documentación en el header.
    - Refactorizar waypts_bappend_vect() teniendo en cuenta la nueva función
    - Nuevo algoritmo en waypts_bread_vect(). Se especifica la posición del vector a leer, y se pueden leer tantos como se especifiquen. Véase WiKi o documentación en el header
    - Ahora waypts_bread_vect() d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
2021-04-30 Add files via upload
    este es el programa casi definitivo solo me falta añadirle la hora
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2021-05-04 Update Robot_CMC.ino
    He cambiado el nombre de los motores para que sean mas intuitivos. Estará apoyado por un dibujo en la wiki.
2021-05-04 Revert "Merge branch 'master' of https://github.com/aigora/twIA_2021-carmap_chikito"
    This reverts commit 7f08e69d75f11177c7c935a2e1b4be8d9dfd47e6, reversing
    changes made to 719d847e9fd0666a87860a5b3fe81cef5ae154fd.
    [Teclado_macros.ino]
2021-05-04 Actualizar command_Arduino_time_s()
    Véase documentación en el prototipo. Añadidas definiciones para hacerlo legible
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2021-05-04 Revert "Revert "Merge branch 'master' of https://github.com/aigora/twIA_2021-carmap_chikito""
    This reverts commit b17fabc26119691a9b115e060adb90355693eaef.
    [Teclado_macros.ino]
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2021-05-06 Añadida versión de programafixluis&fer.cpp
    Limpieza de código
    Bugfix: ahora el input de números escanea n, no n+1 comandos
    Bugfix: caracteres sueltos en stdin que dan por saco
    Warning fix: por el casting del gotoxy, ahora acepta enteros pequeños (`short`)
    Warning fix: tontunas de VS con los chars
    Comentario aparte:
    @luisrubio27 , el código parece bastante optimizable, pero eso es lo de menos. Por ej., lineas 155 a 157 parece que se repiten varias veces.
    @Fer014 , la distancia ¿es calculada respecto del origen? Pq cuando le das al norte y luego al sur sigue aumentando
    Cosas que hay que cambiar:
    - Que sea un poco más legible la entrada, o intuitiva, con menos texto, bien c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
2021-05-15 Update programafixluis&fer-3.cpp
    -Solucionado error del mapa: ahora todos los movimientos del robot en el mapa se ven uniformes, no hay unos más grandes que otros.
    Bug: cuando mueves un poco el robot y después lo regresas al origen, a veces hay un error muy pequeño en los decimales al mostrar la distancia respecto del origen, pero idk
    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
2021-05-24 Bugfix: no se ejecutan funciones al apretar una tecla cualquiera
    Antes se volvía a mandar el mismo comando, ahora se comprueba que la ejecución de comandoArduino_wrapper es válida, y si lo es se ejecuta el resto del código.
2021-05-24 Arreglao el engrish :uk: :arrow_lower_right:
2021-05-25 Añadir proyecto de KiCad e imagen del esquema, adaptar .gitignore
    [CarMap.kicad_pcb, CarMap.sch]
